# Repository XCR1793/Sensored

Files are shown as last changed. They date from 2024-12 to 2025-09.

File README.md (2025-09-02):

# Sensored
A simple very dense sensor module which includes an IMU and an environmental sensor. The system is designed to be easily integrated with any other projects and is relatively cheap to fabricate.

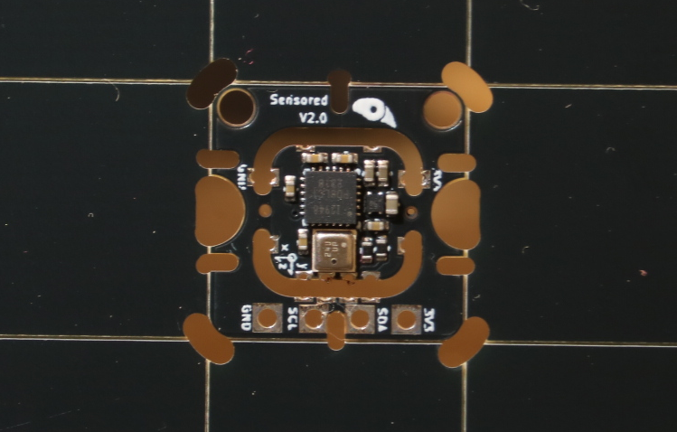
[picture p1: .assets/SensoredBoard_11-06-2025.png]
Project_Image


## Features
* IMU: ICM20948 (3 Axis Accelerometer + 3 Axis Gyroscope + 3 Axis Magnetometer)
* ENV: BME280 (Temperature + Humidity + Pressure)
* I2C: Internally Pulled Up 10K
* LDO: 3V3 input power is stepped down to 1.8v for other IC functions

## [Embedded](/Embedded/README.md)
The Sensored board integrates two key devices: the ICM20948, a 9-axis motion sensor, and the BME280 for environmental monitoring. Designed for direct integration onto host boards, it operates on 3.3 V with onboard regulation for the IMU, providing a compact foundation for motion and environmental sensing in embedded systems.

## Roadmap
* Milestones: Fabricating V1.0
* Milestones: Confirmed V1.0 circuit design
* Milestones: Fabricating V2.0
* Milestones: Confirmed V2.0 circuit design

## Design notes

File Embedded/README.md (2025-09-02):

# Sensored - Embedded
There are 2 sensors on the Sensored board, these are the ICM20948 and the BME280. The ICM20948 is a compact IMU with 3 axis accelerometer, gyroscope and magnetometer. The BME is a sensitive sensor that measures temperature, pressure and humidity. The I2C lanes are pulled up to 3V3 via 10K resistors. There is also a 1V8 LDO for converting 3V3 to 1V8 as the ICM20948 requires it for its internal VDDIO pin. DO NOT EXCEED 3V3 on the 3V3, SDA and SCL pins, this device also DOES NOT HAVE reverse voltage protection as it doesnt require one. The board is designed to be soldered directly onto other boards and is not ment to be an externally mounted module. You can do this by removing the middle "Island" from the outer ring.

Here are the specifications for the ICM-20948 and BME280 sensors.

## ICM-20948
| Sensor | Axis | Full-Scale Range | Sensitivity 
| --- | --- | --- | ---
| Accelerometer | X, Y, Z  | ±2g, ±4g, ±8g, ±16g | 16384, 8192, 4096, 2048 LSB/g
| Gyroscope | X, Y, Z  | ±250, ±500, ±1000, ±2000 °/s | 131, 65.5, 32.8, 16.4 LSB/°/s
| Magnetometer  | X, Y, Z  | ±4900 µT | 0.15 µT/LSB

## BME280
| Sensor | Parameter | Measurement Range | Resolution
| --- | --- | --- | ---
| Pressure | Pressure | 300 to 1100 hPa | 0.18 Pa
| Temperature | Temperature | -40 to 85 °C | 0.01 °C
| Humidity | Humidity | 0 to 100 %RH | 0.008 %RH

---

The entire board was routed on one side with a single ground plate to reduce EMI. The inner island is 8mm x 8mm which is a very small footprint and should fit in nearly any project. The fabricated board is using a 0.8mm board thickness rather than the standard 1.6mm as this also reduces the overall 3D footprint. All of the LCSC BOM part numbers are included within the KiCAD file and can be directly converted to Gerber + drill + placement files and sent off to JLCPCB to be manufactured (JLCPCB was used as they are cheap). The cost is roughly $150 AUD for 5 fully assembled boards therefore its ~$30 / Board.

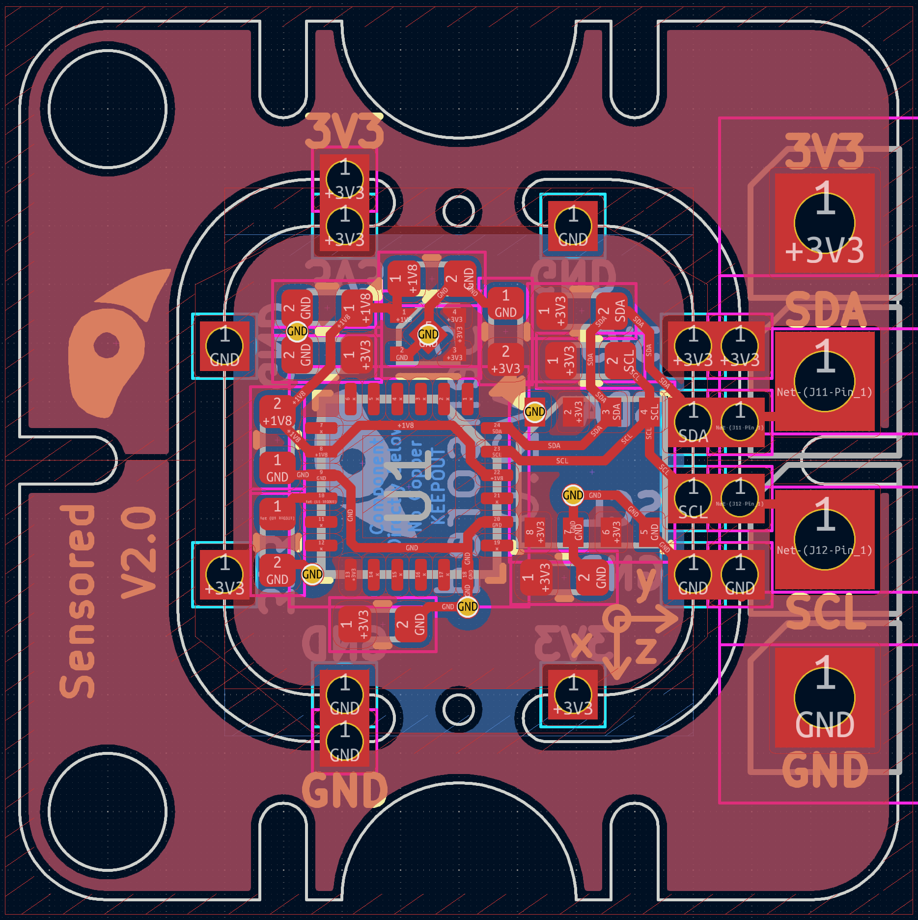
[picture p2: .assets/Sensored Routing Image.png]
Embedded_Capabilities


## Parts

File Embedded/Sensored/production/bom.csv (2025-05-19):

Designator | Footprint | Quantity | Value | LCSC Part #
C1, C3, C4, C6, C8 | 0402 | 5 | 0.1uF | C1525
C11, C9 | 0402 | 2 | 1uF | C52923
C13 | 0402 | 1 | 10uF | C15525
J1, J11 | 1mm Pads | 2 | SDA
J10, J12 | 1mm Pads | 2 | SCL
J13, J15, J2, J4, J6, J8 | 1mm Pads | 6 | 3V3
J14, J16, J3, J5, J7, J9 | 1mm Pads | 6 | GND
R1, R2 | 0402 | 2 | 10K | C25744
TP1 | PinHeader_1x01_P2.54mm_Vertical | 1 | 3V3
TP2 | PinHeader_1x01_P2.54mm_Vertical | 1 | SDA
TP3 | PinHeader_1x01_P2.54mm_Vertical | 1 | SCL
TP4 | PinHeader_1x01_P2.54mm_Vertical | 1 | GND
U1 | InvenSense_QFN-24_3x3mm_P0.4mm | 1 | ICM-20948 | C726001
U3 | Bosch_LGA-8_2.5x2.5mm_P0.65mm_ClockwisePinNumbering | 1 | BME280 | C92489
U4 | UDFN-4-1EP_1x1mm_P0.65mm_EP0.48x0.48mm | 1 | TLV74318PDQNR3 | C2860843

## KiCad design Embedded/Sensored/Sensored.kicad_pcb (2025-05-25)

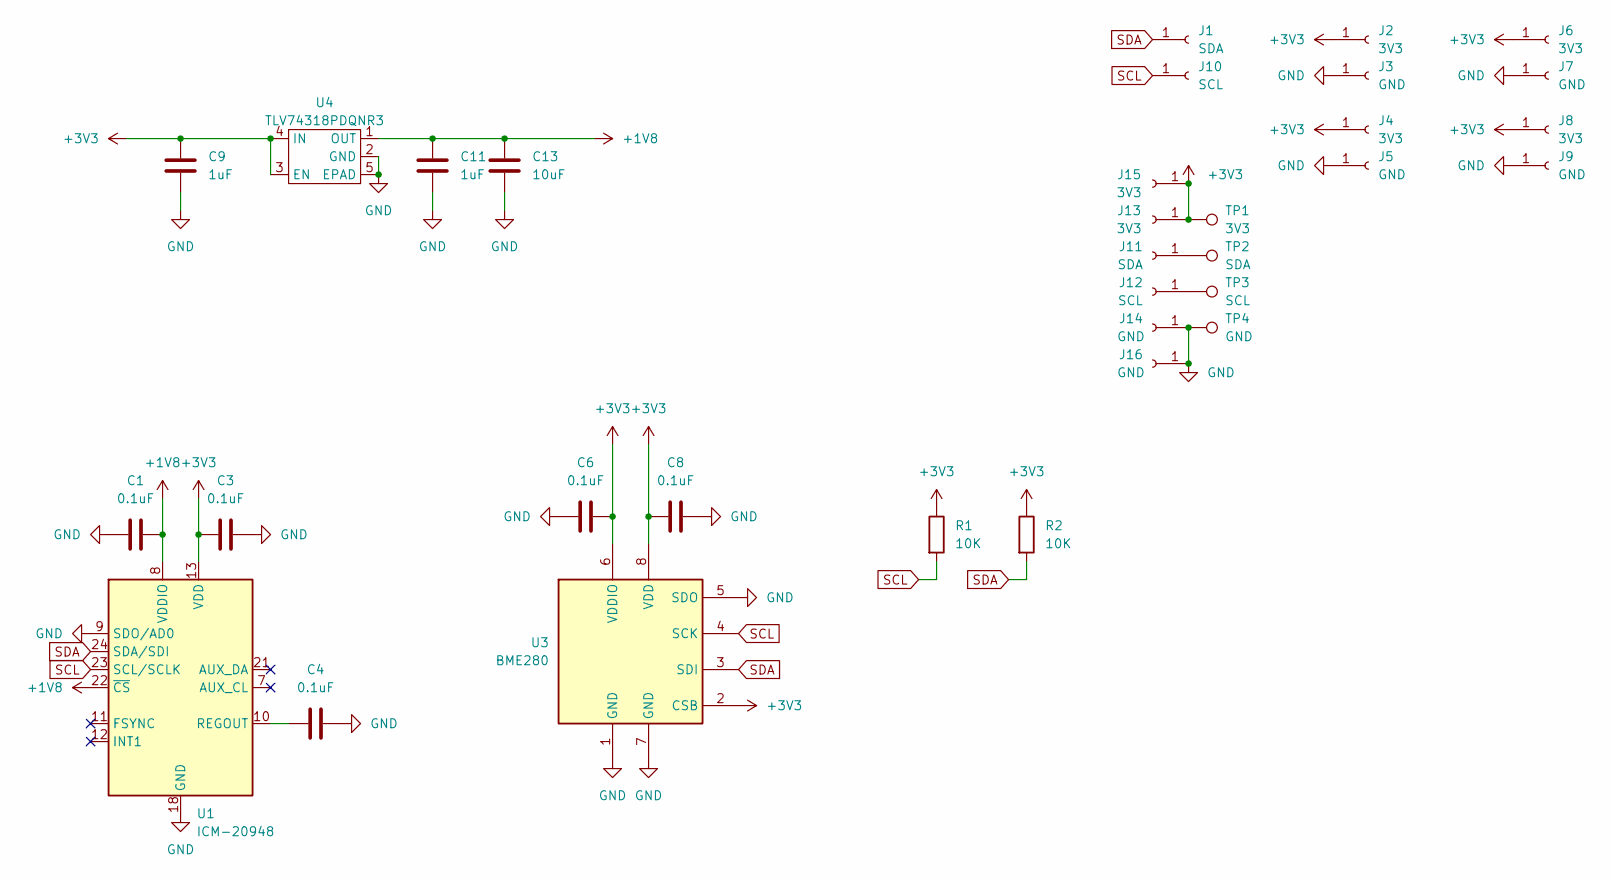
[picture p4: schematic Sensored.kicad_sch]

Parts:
C1, C3, C4, C6, C8: 0.1uF; C_0402_1005Metric; LCSC C1525
C9, C11: 1uF; R_0402_1005Metric; LCSC C52923
C13: 10uF; C_0402_1005Metric; LCSC C15525
J1, J11: SDA; 1mm Pads
J2, J4, J6, J8, J13, J15: 3V3; 1mm Pads
J3, J5, J7, J9, J14, J16: GND; 1mm Pads
J10, J12: SCL; 1mm Pads
R1, R2: 10K; R_0402_1005Metric; LCSC C25744
TP1: 3V3; PinHeader_1x01_P2.54mm_Vertical
TP2: SDA; PinHeader_1x01_P2.54mm_Vertical
TP3: SCL; PinHeader_1x01_P2.54mm_Vertical
TP4: GND; PinHeader_1x01_P2.54mm_Vertical
U1: ICM-20948; InvenSense_QFN-24_3x3mm_P0.4mm; LCSC C726001
U3: BME280; Bosch_LGA-8_2.5x2.5mm_P0.65mm_ClockwisePinNumbering; LCSC C92489
U4: TLV74318PDQNR3; UDFN-4-1EP_1x1mm_P0.65mm_EP0.48x0.48mm; LCSC C2860843

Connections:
+1V8: C1.2, C11.1, C13.1, U1.8 (VDDIO), U1.22 (~CS), U4.1 (OUT)
+3V3: C3.1, C6.2, C8.1, C9.1, J2.1, J4.1, J6.1, J8.1, J13.1, J15.1, R1.1, R2.1, TP1.1, U1.13 (VDD), U3.2 (CSB), U3.6 (VDDIO), U3.8 (VDD), U4.3 (EN), U4.4 (IN)
GND: C1.1, C3.2, C4.2, C6.1, C8.2, C9.2, C11.2, C13.2, J3.1, J5.1, J7.1, J9.1, J14.1, J16.1, TP4.1, U1.9 (SDO/AD0), U1.18 (GND), U1.20 (GND), U3.1 (GND), U3.5 (SDO), U3.7 (GND), U4.2 (GND), U4.5 (EPAD)
unnamed: J11.1, TP2.1
unnamed: J12.1, TP3.1
unnamed: C4.1, U1.10 (REGOUT)
SCL: J10.1, R1.2, U1.23 (SCL/SCLK), U3.4 (SCK)
SDA: J1.1, R2.2, U1.24 (SDA/SDI), U3.3 (SDI)

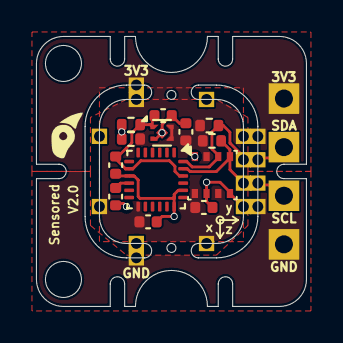
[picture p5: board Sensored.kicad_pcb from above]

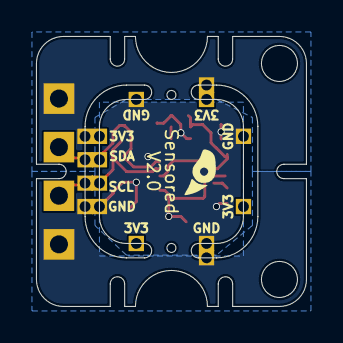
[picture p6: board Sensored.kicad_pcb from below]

Board: 2 copper layers, 15.0 x 15.0 mm, 33 parts (10 on the bottom side), 8 nets.

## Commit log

2024-12-20 Added Some Ideation
    [Project.kicad_pcb, Project.kicad_sch, Sensored.kicad_pcb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]
2024-12-21 Added Castellated Pins & Removed Micro SD Card
    [Sensored.kicad_pcb, Sensored.kicad_sch]
2024-12-21 Added Stabiliser GND Pins & Finished Routing
    [Sensored.kicad_pcb, Sensored.kicad_sch]
2024-12-21 Added Markings & Component Adjustment
    [Sensored.kicad_pcb]
2024-12-21 Added CAD Model
    [Sensored.step]
2024-12-21 Replaced Side GND Pins with GND EPad
    [Sensored.kicad_pcb, Sensored.kicad_sch, Sensored.step]
2024-12-21 Updated CAD Origin & Materials
    [Sensored.step]
2024-12-22 Generated BOM, JLCPCB Assembly Parts, Production Files, Drill Positions
    [Sensored-B_Cu.gbr, Sensored-B_Mask.gbr, Sensored-B_Paste.gbr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]
2024-12-22 Added Pick & Place Component Position Files
    [Sensored-bottom-pos.csv, Sensored-top-pos.csv]
2024-12-23 Optimised JLCPCB Specific Parts
    [Sensored-B_Cu.gbr, Sensored-B_Mask.gbr, Sensored-B_Paste.gbr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]
2024-12-25 Added Initial Documentation
    [Sensored.step]
2025-05-16 Removed Obsolete Files
    [Sensored-B_Cu.gbr, Sensored-B_Mask.gbr, Sensored-B_Paste.gbr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]
2025-05-16 Added System Connection Diagram, Layout Guide & Replacement PCB Design Ideation
2025-05-17 Modified Outline & Component Placements for V2
    [Sensored.kicad_pcb, Sensored.kicad_sch]
2025-05-17 Modified Component Placement & Added Adapting Pads
    [Sensored.kicad_pcb, Sensored.kicad_sch]
2025-05-17 Added Component Routing
    [Sensored.kicad_pcb, Sensored.kicad_sch]
2025-05-19 Added Orientation Marker
    [Sensored.kicad_pcb, Sensored.kicad_sch]
2025-05-19 Verified LCSC Components
    [Sensored.kicad_pcb, Sensored.kicad_sch, bom.csv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]
2025-05-20 Modified Layout for JLCPCB
    [Sensored.kicad_pcb, Sensored.kicad_sch]
2025-05-21 Modified Board Edge Slots to be shorter
    [Sensored.kicad_pcb, positions.csv]
2025-05-23 Modified Board Edge to 0.8mm Tolerance
    [Sensored.kicad_pcb, positions.csv]
2025-05-23 Modified the Pin Positions
    [Sensored.kicad_pcb, positions.csv]
2025-05-25 Modified Via Positions to prevent potential component floating
    [Sensored.kicad_pcb]
2025-09-02 Removed Software section as it is no longer needed
    Sensor driving instructions and register maps are available in the ICM20948 and BME280 datasheets.
